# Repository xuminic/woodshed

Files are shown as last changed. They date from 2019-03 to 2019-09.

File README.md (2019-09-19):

# Wood Shed -- Howto build a wood shed

<table>
  <tr>
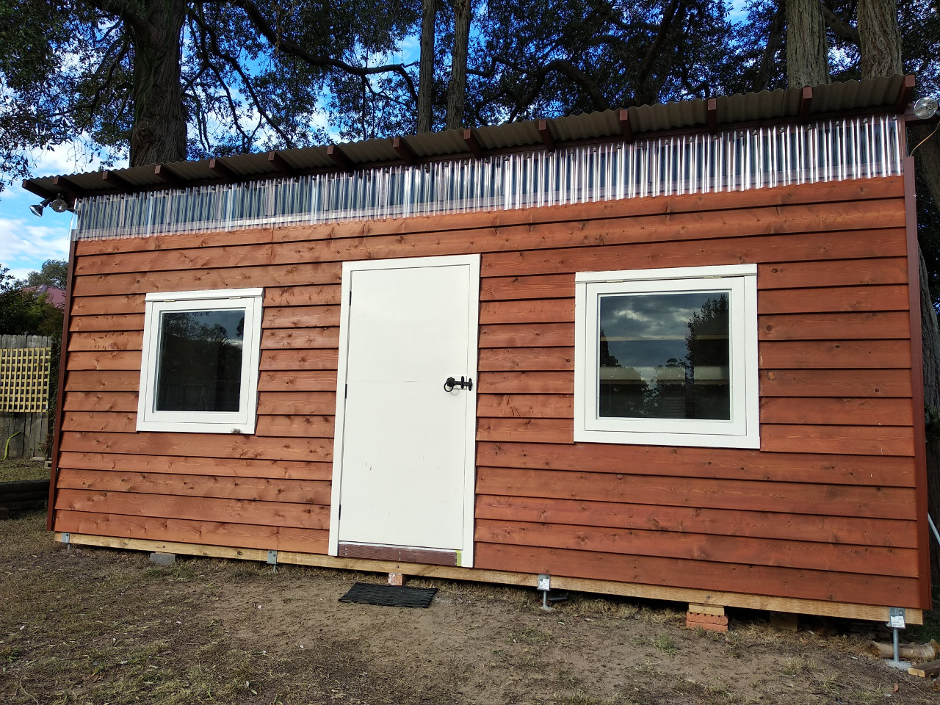
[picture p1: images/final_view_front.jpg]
Front View
    <td colspan="2"></td>
  </tr>
  <tr>
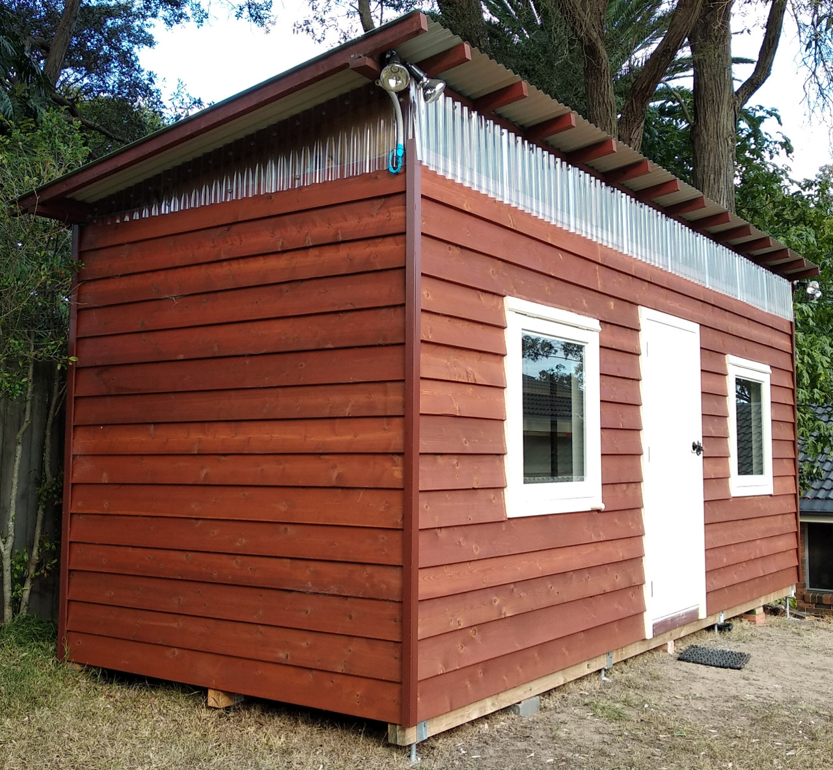
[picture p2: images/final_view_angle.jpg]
Angle View
    <td align="left"></td>
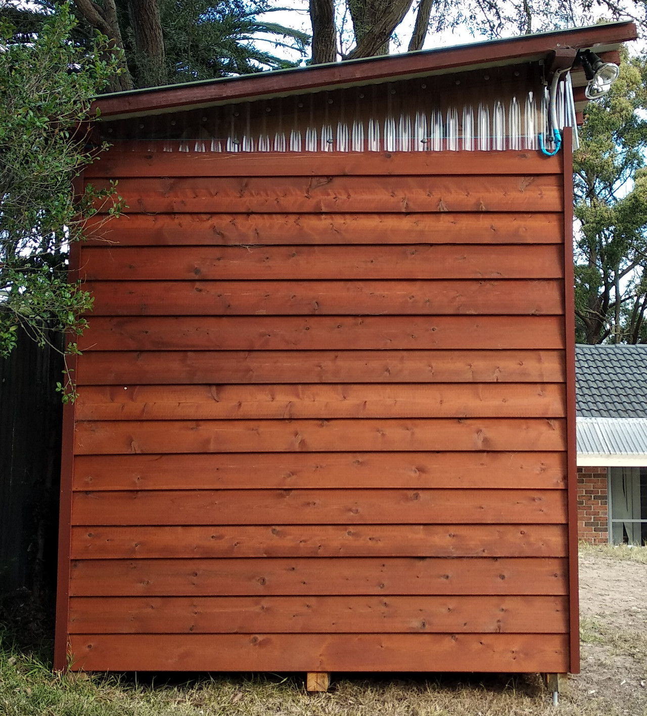
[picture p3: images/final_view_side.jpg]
Side View
    <td align="right"></td>
  </tr>
  <tr>
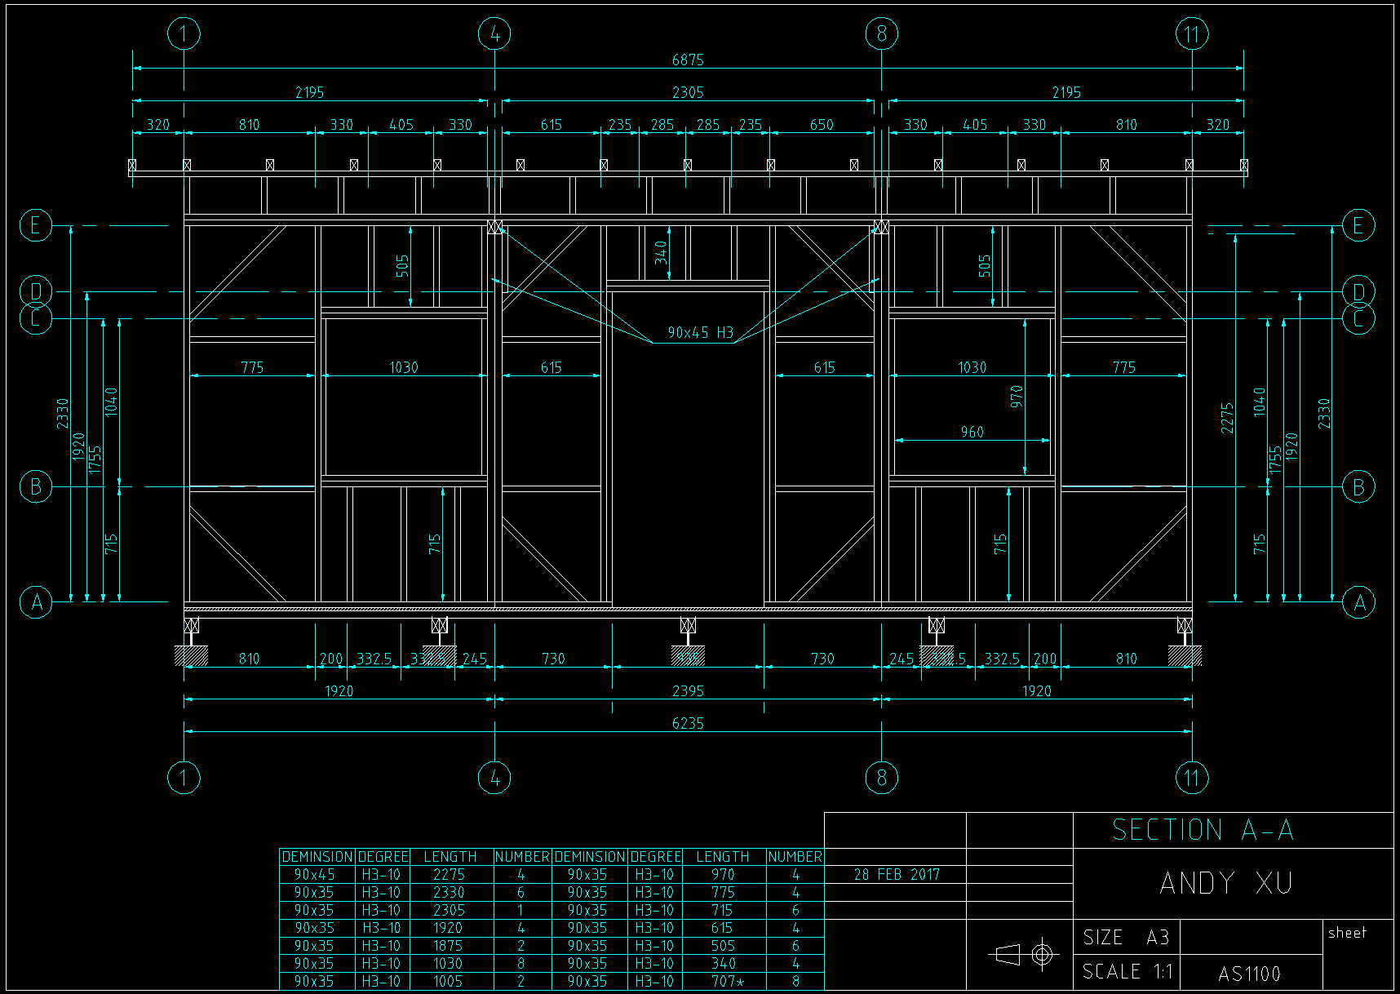
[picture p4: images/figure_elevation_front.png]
Front Blueprint
    <td align="left"></td>
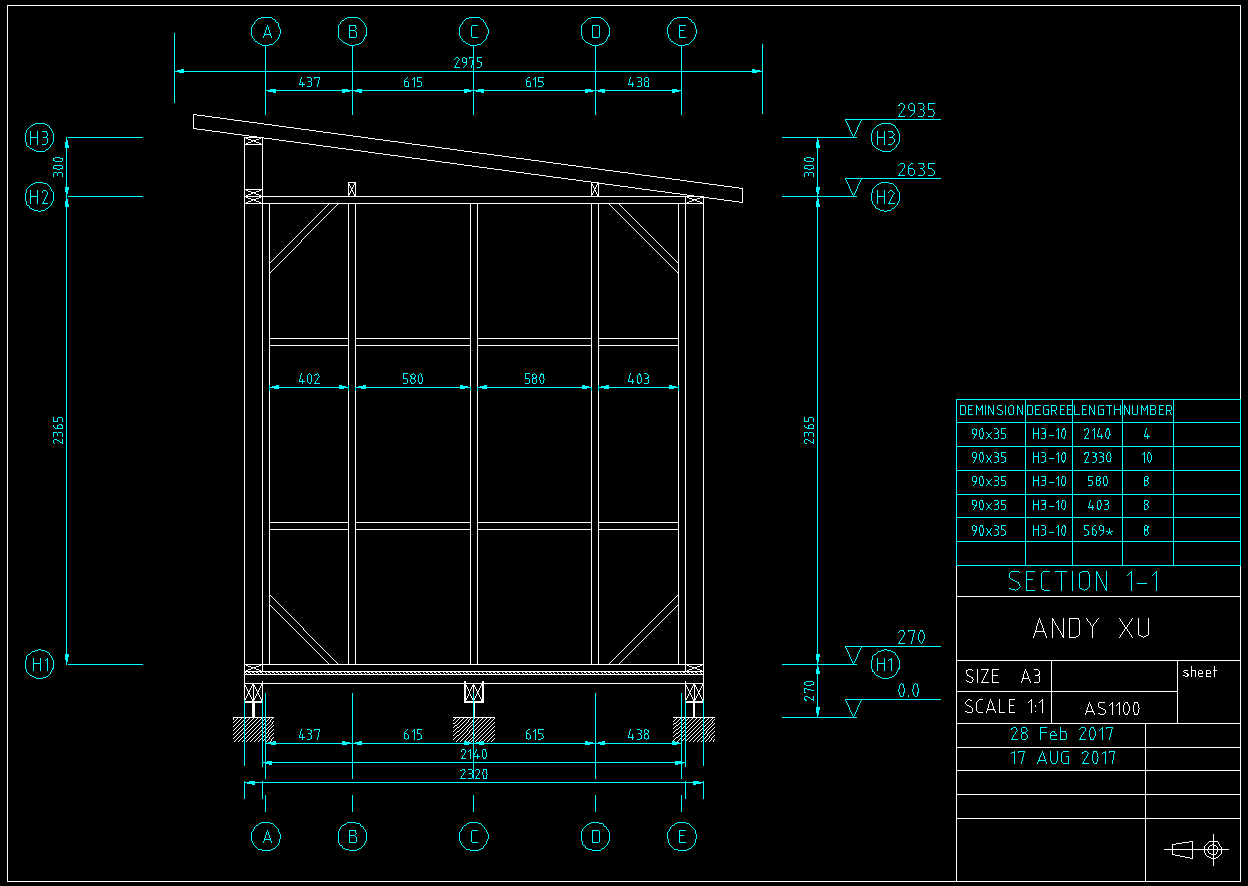
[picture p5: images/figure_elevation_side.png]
Side Blueprint
    <td align="right"></td>
  </tr>
</table>

This project shares my plan, progress and experience to build a small garden shed 
with wood frames and cladding. The roof is ColorBond metal and the foundation is
post anchor and concrete. The area is roughly 6 meters by 2.4 meters and the height
is 3 meters. The BOM budget was $4000 AUD and apparently was overrun, 
not sure the detail number, perhaps by 30%-40%. 

Most important part in this project is the plan made with LibreCAD. 
If you are a computer monkey who knows CAD software pretty well, and willing to
do some manual work in your backyard to kill some weekends, this project could be
a good start for you. You can easily shape it to fit your purpose.
If you don't know how to use LibreCAD, you may still find some useful references
from this project. I'll also export some PDF file from the plan.

## Motivation

I need a shed to host garden tools, being storage room and a sometime study room.
Metal shed is cheap but need the concrete slab to be assembled. Some wood sheds 
can be purchased from store. But they are not suitable for the slope.
Apparently whatever I do I need to build a flat foundation first. The easiest
way to build a foundation is deck foundation, just some anchor posts and timbers.
Naturally it would be quite strong if stick some timber frames on the timber
foundation and a shed could come into being, just need to do some detail design.
LibreCAD is a cross platform open sourced 2D CAD software which is perfect for 
my purpose. It supports layers so you can easily see through different profiles.
It is also convenient to design something not available in Internet, like this
one, had a 3:1 length width ratio.

## Disclaimer

This project is released under MIT License. Please find the attached LICENSE file.

This project is just for fun and for non-commercial use. All information 
in this project were deduced from basic physics or searched from websites. 
I am no architecture nor home builder. There is absolutely no warranty for the project.

There are some URLs and products descriptions linked to some commercial websites.
Those are all examples for helping understanding. There is no advertisement or 
promotion for ANY commercial entities. You are free to choose any suppliers for 
any brands of products.

When you get into the construction, do not forget to wear the proper protections
like helmet, goggles, etc. Be extremely careful with power saws and air tools,
which could easily cut some fingers off in no time. Be extremely careful with 
power lines, which could cause fire or even electrocution. Keep kids and dogs away
from work site.

Before you start, check with your local council to make sure the shed can be legally built.
Different council has different regulations regarding to the dimension.

The frame section is 90x35mm and the space is based on 600mm, which is commonly 
used in house building. However I do not know how strong it can resist against the wind
so please do not build it in tornado area.

## Files and Folders

Note that for some reason these .dxf files may suffer display issue in LibreCAD 2.1.x.
By such circumstance please try open them with LibreCAD 2.0.x.

    .
    ├── 01_foundation           # the design and details of the foundation and floor.
    ├── 02_frames               # the design and details of the structural frames.
    ├── 03_roof                 # the design and details of the roof structure.
    ├── 04_cladding             # the design and details of the timber cladding.
    ├── 05_interior             # some details of the interior design and utility shelf.
    ├── elevation_front.dxf     # the all in one CAD of the elevation in the front view.
    ├── elevation_side.dxf      # the all in one CAD of the elevation in the side view.
    ├── plan.dxf                # the all in one CAD of the plan view.
    ├── supply.ods              # the pretty rough BOM breakdown, don't rely on its price list.
    ├── images
    ├── LICENSE
    └── README.md

## Nail or Drill

When fastening timber frames, joinsts or beams together, professional trademen
prefer to use nails. The cost is low, probably $20/1000 nails. It's super fast
with an air nailer, for example, the project like the shed can be done in one day
in an experienced hand. However nailing is not as simple as it looks like. 
It needs skill. The nails could be bent or crooked. Thumbs are always under threaten.
Air nailer is not easy to use either. I have a compressor and frame nailer
and found it's quite hard to control the accuracy and direction. It always goes to
the unexpected place. It's heavy and loud, sometimes splits timbers. 
I reckon one needs thousands of nailing practise to get used to that.

Finally I gave up the frame nailer, I still use brad nailer by the way, but using
screws instead. Screws are very strong and very easy to control. It's accurate because
there's no impact while driving. It needs more money than nails, yet still only 
a tiny part in the whole project. Positively thinking, when you don't need the 
shed any longer, in theory it could be disassembled with a screwdriver.

For better performance, I recommands the Bugle Head Batten Screw, galvanised, 
heavy duty 14 gauge with hexagonal key drive head for high torque fastening.
Perfect for the 18V screwdriver.

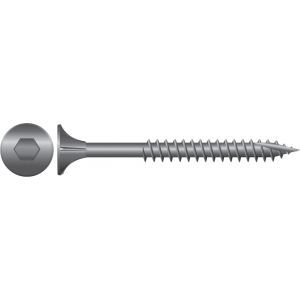
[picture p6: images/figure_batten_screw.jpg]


Most frame timber can be done with 65mm screws. The 100mm screws used to fasten
the frame on the floor. The overcross beam is 90x90 so there are 16 screws 
to be 125mm+. To get an accurate screwing, I always drill a pilot hole before
driving. For those longer than 100mm, the very long drill is needed.

## Power Tools in Need

Those power tools are very important to save your time and efforts. 
The professional tools are certainly the best. 
However even the cheapest one will also be the great helper.
The followed list is not a shopping guide. All pictures and brands are references only.
You may choose whatever you'd like in your local suppliers within your budget.

* Mitre saw is a must-have. It can easily cut timbers in 90 degree or 45 degress accurately in seconds.

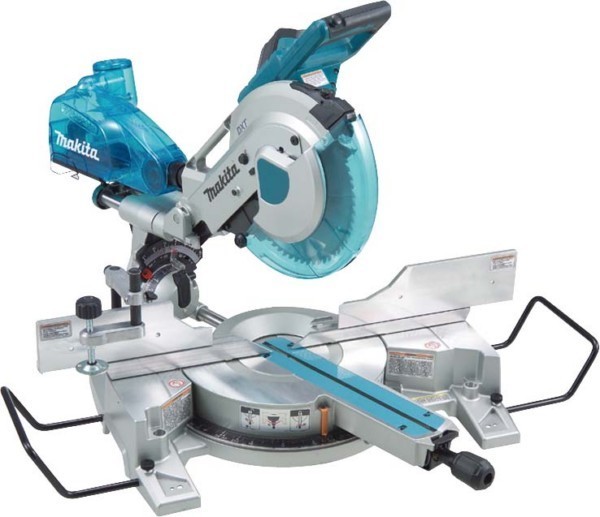
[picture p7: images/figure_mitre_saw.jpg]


* 18V drill set, normally includes an impact drill and screw driver. 
The 18V drill set are amazingly powerful and portable. I used it to drive a 150mm screws quite often
while 10V driver simply stuck.

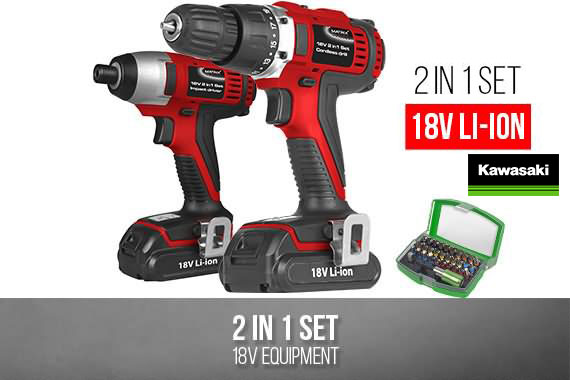
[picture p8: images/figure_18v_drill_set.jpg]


* Circular saw is almost the every-one-saw. You will need it when you cut the floor board.
It's light and easy to use. Sometimes it's more flexible when cutting large area boards.

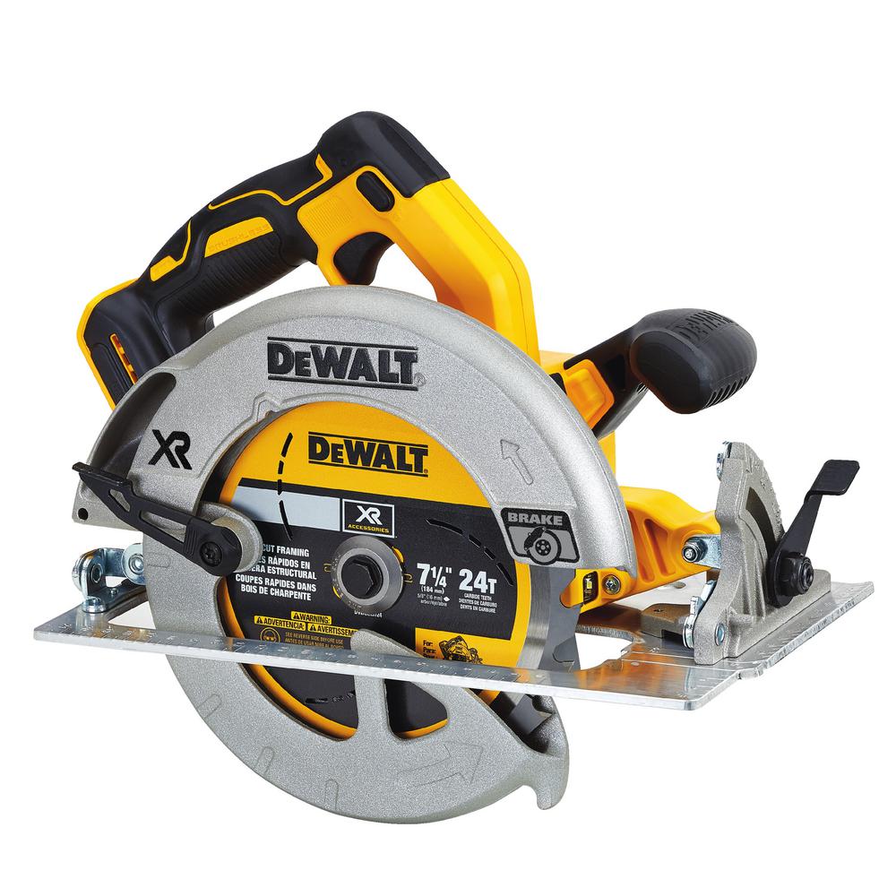
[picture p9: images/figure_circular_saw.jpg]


* Table saw is optional. It's more accurate than circular saw especially while cutting 
narrow or strip of boards. You will find it's much quicker while cutting the cladding board in length.

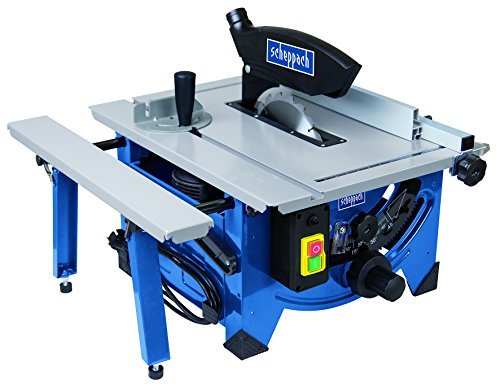
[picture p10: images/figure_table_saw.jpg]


* Drill press is optional. It helps to drill a vertical hole accurately. 
Perfect for the obsessive-compulsive personality.

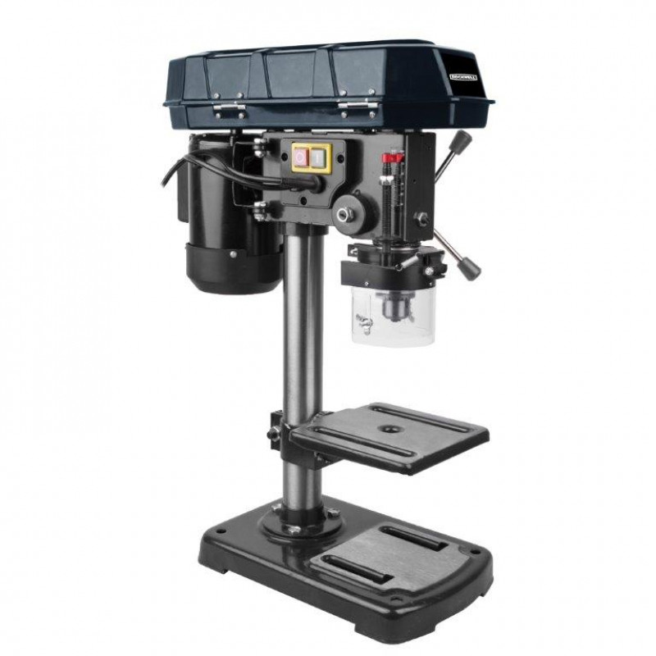
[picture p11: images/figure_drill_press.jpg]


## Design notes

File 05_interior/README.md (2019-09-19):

# Interior Improvement

As a garden shed, it was ready to use after exterior cladding. 
Morever than that I did a little upgrade to make it as cosy as a sometime reading room.
The upgrade includes the interior cladding, insulation, floor tiles, utility shelf and painting.

## Interior Cladding and Insulation

There are many building materials to be installed in door as the wall. 
Wood or laminate floor for example can be nice and stylish.
I chosed the plasterboard simply because its low price and been widely used.
The trade mark of the plasterboard is Gyprock, which is made of paper and plaster.

Before installing the plasterboard sheet, I prefer to install some supports around the edge.
It's not a have-to. Many builders choose to ignore it and install the plasterboard anyway.
But I feel it would be stronger with these extra supports.

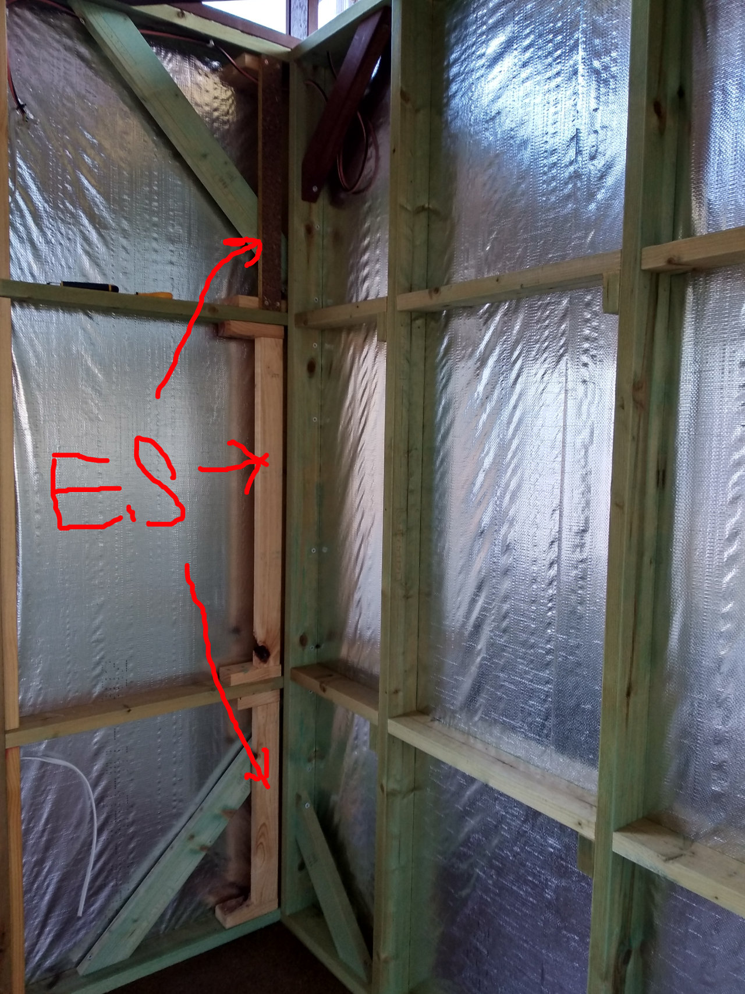
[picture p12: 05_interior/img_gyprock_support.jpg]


The red arrows point to the extra supports. Meanwhile all spaces between the studs were filled
with 90mm Earthwool. I don't know why I was so obsessive compulsively install the insulation
in a shed, probably by fashion. It's not expensive any way.

<table>
  <tr>
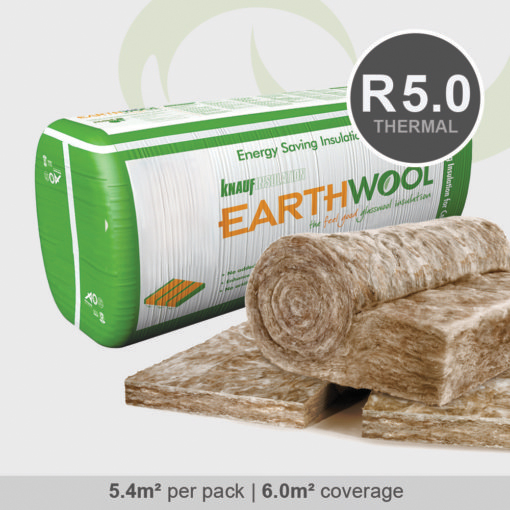
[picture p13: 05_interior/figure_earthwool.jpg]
Earthwool
     <td align="left"></td>
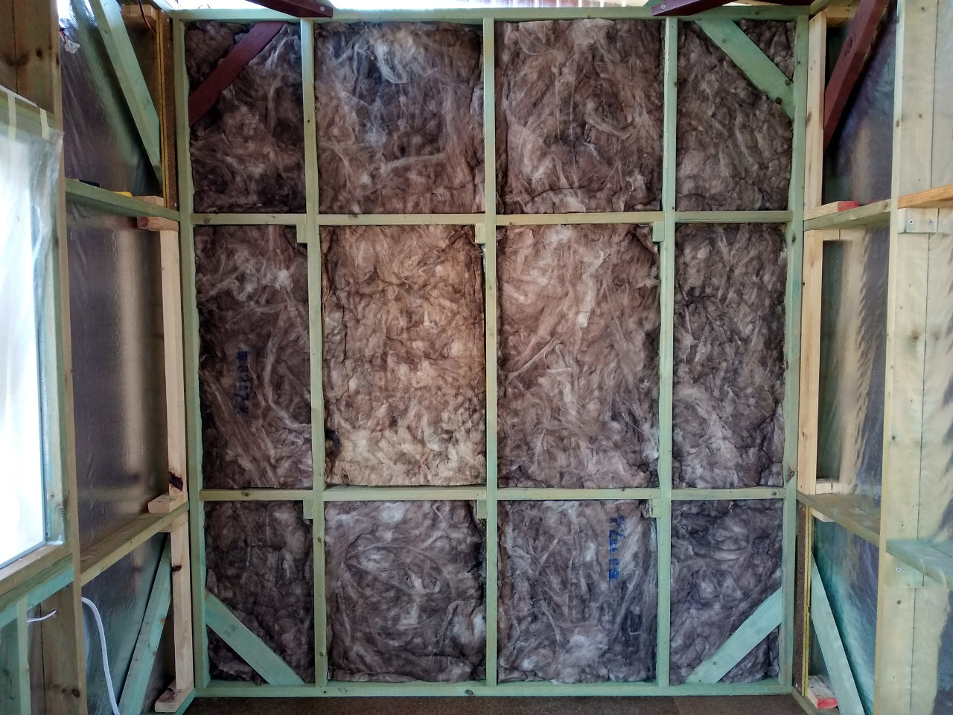
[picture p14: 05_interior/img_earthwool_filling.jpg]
Insulation
     <td align="right"></td>
  </tr>
</table>

If you want to wire power cable behand the wall, it's time to do so before gluing the plasterboard.
Generally the plasterboard should be glued to the stud with Stud Adhesive, only the edges been nailed.

<table>
  <tr>
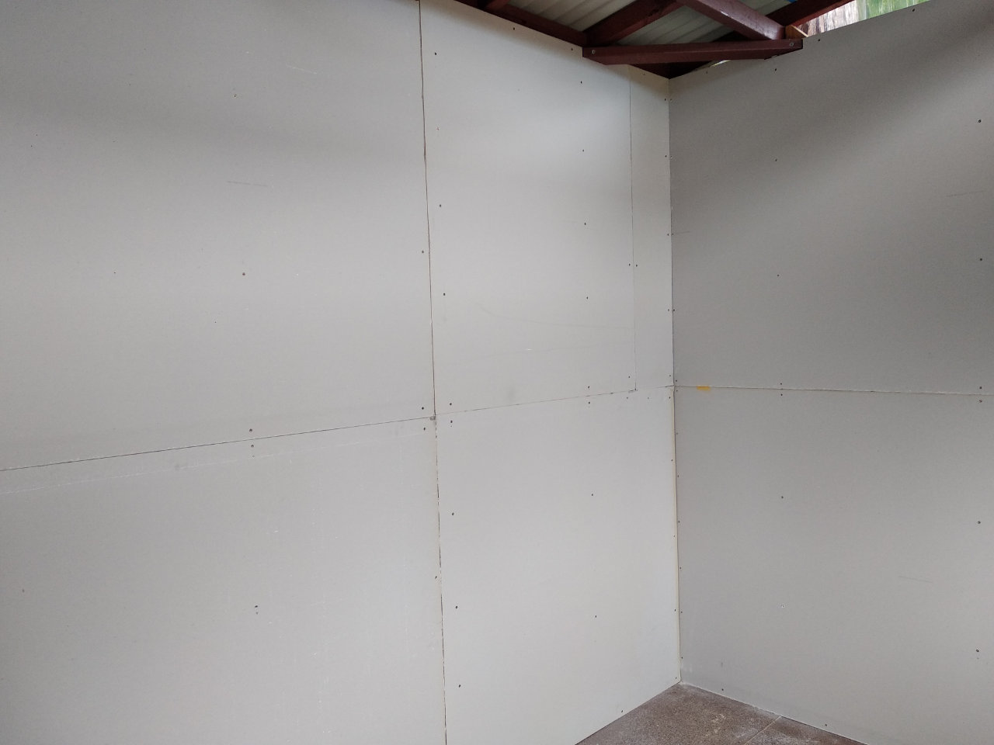
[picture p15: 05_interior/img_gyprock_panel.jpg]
Gyprock
     <td align="left"></td>
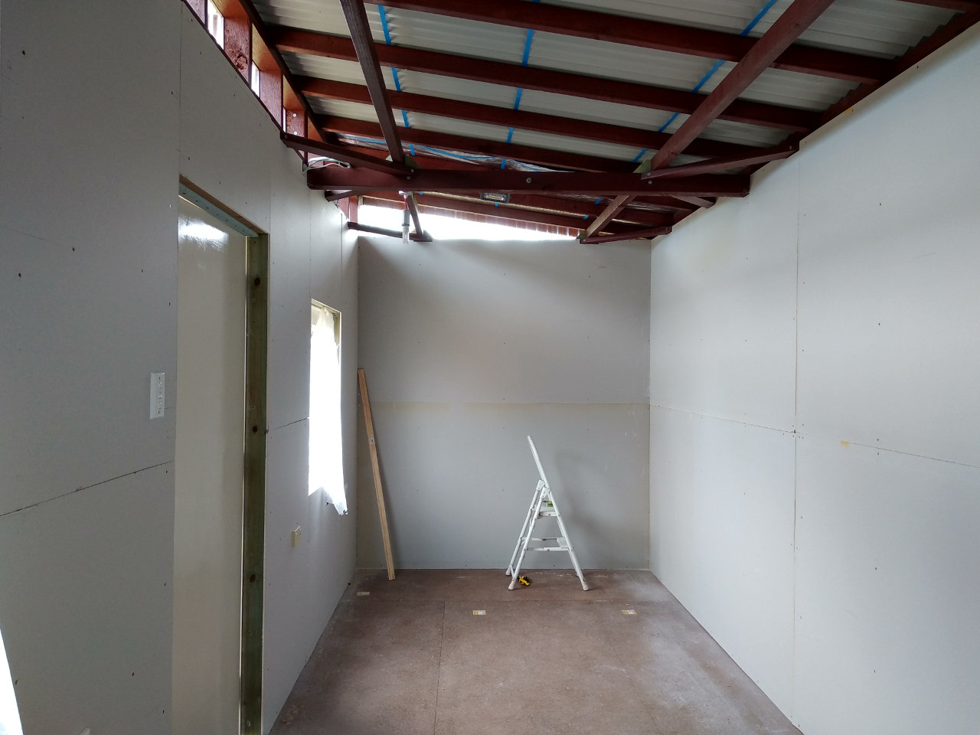
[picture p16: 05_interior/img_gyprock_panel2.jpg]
Gyprock
     <td align="right"></td>
  </tr>
</table>

The joints between plasterboards will be taped with Paper Jointing Tape and filled with joint Compound.
The process was quite tedious because I have to keep pasting and sanding to get a smooth finishing.

<table>
  <tr>
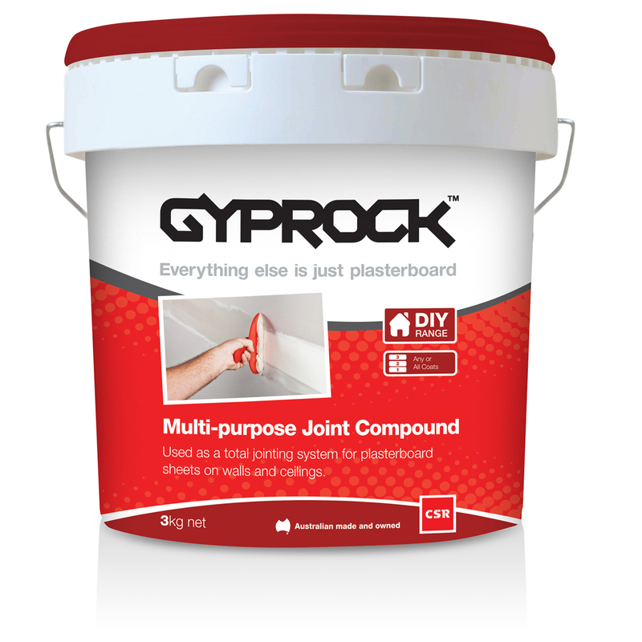
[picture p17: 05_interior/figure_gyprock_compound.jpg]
Gyprock Filler
     <td align="left"></td>
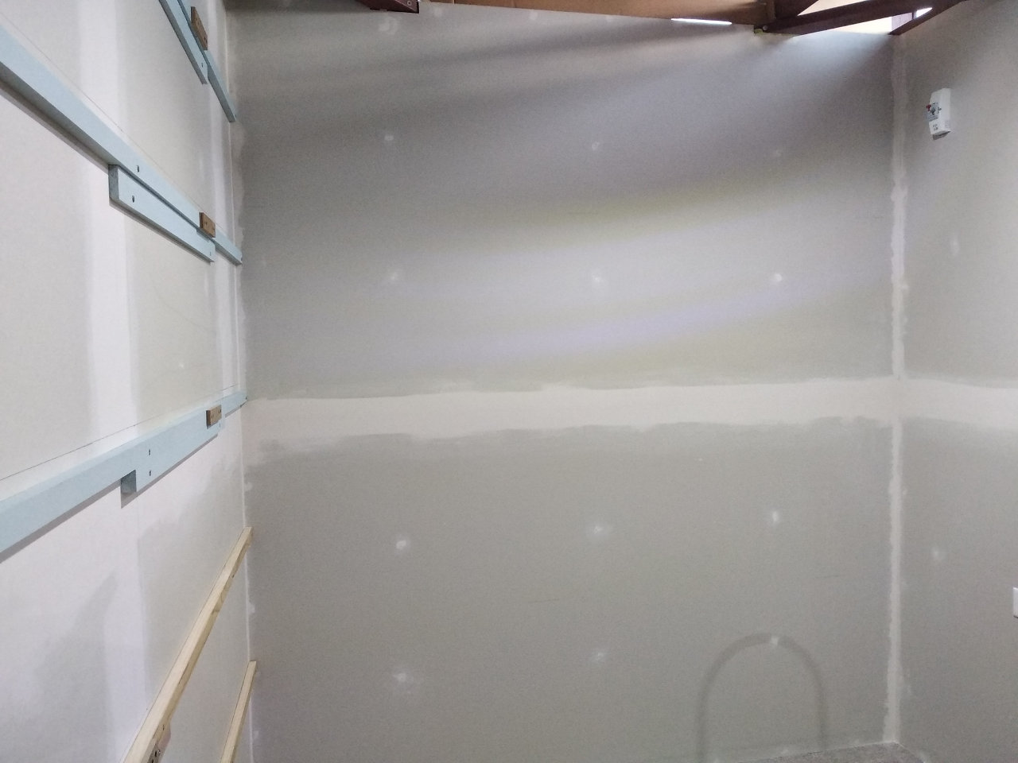
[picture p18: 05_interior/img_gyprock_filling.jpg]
Gyprock Filled
     <td align="right"></td>
  </tr>
</table>

Then the wall was painted.

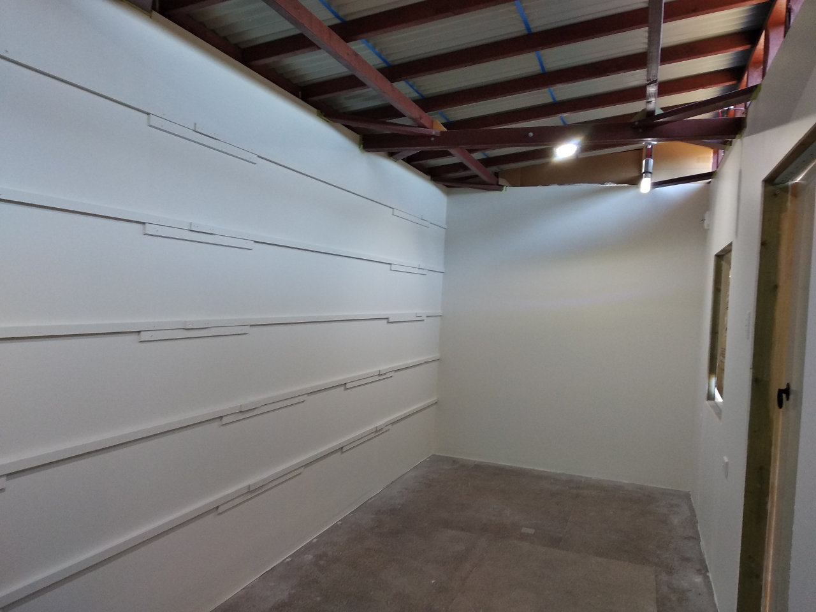
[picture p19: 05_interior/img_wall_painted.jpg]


## Floor Tiling

No more to say, just lay some tiles if you like, or leave it as-is.

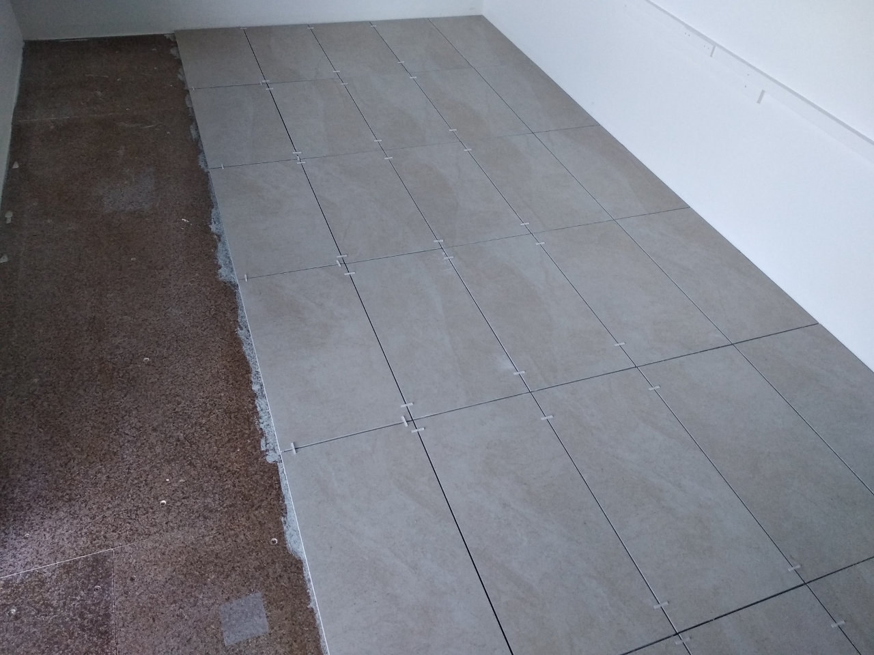
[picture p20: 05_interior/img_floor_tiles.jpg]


## Utility Shelf

The utility shelf is the most important component in the shed. After all it's a storage room.
This featured shelf has the same length to the shed. It occupied a whole wall. 
The back side supports of the shelf were nailed into the stud. The front side supports were installed 
to the frame timber, which stand on the floor and nailed to the roof structure.
The shelf is rigid and heavy duty.



The width of the shelf is slightly larger than common 300mm shelf; it's almost 400mm.
I think it's more versatile to use.

<table>
  <tr>
     <td align="left">Front View</td>
     <td align="right">Side View</td>
  </tr>
</table>

First, nail the supporting beam to the studs against the wall. 
I used the 42x22mm timber as the supporting beam.

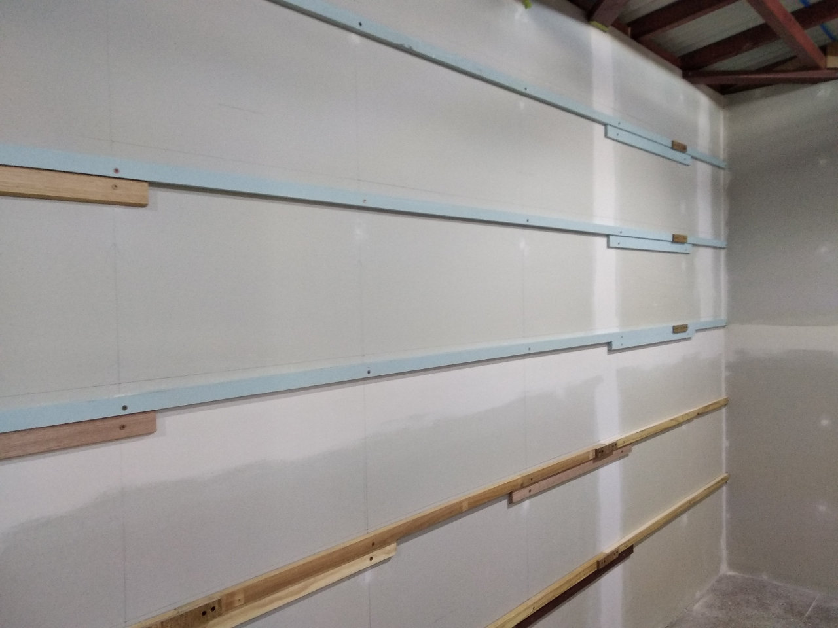
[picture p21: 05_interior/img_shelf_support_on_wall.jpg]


Second, install the posts. The posts are structural timber of 70x35mm. 
They stand on the floor. The ground end was nailed to a corner support.
The corner supports are also nailed to the studs. 
Note that each post must face to the studs.

<table>
  <tr>
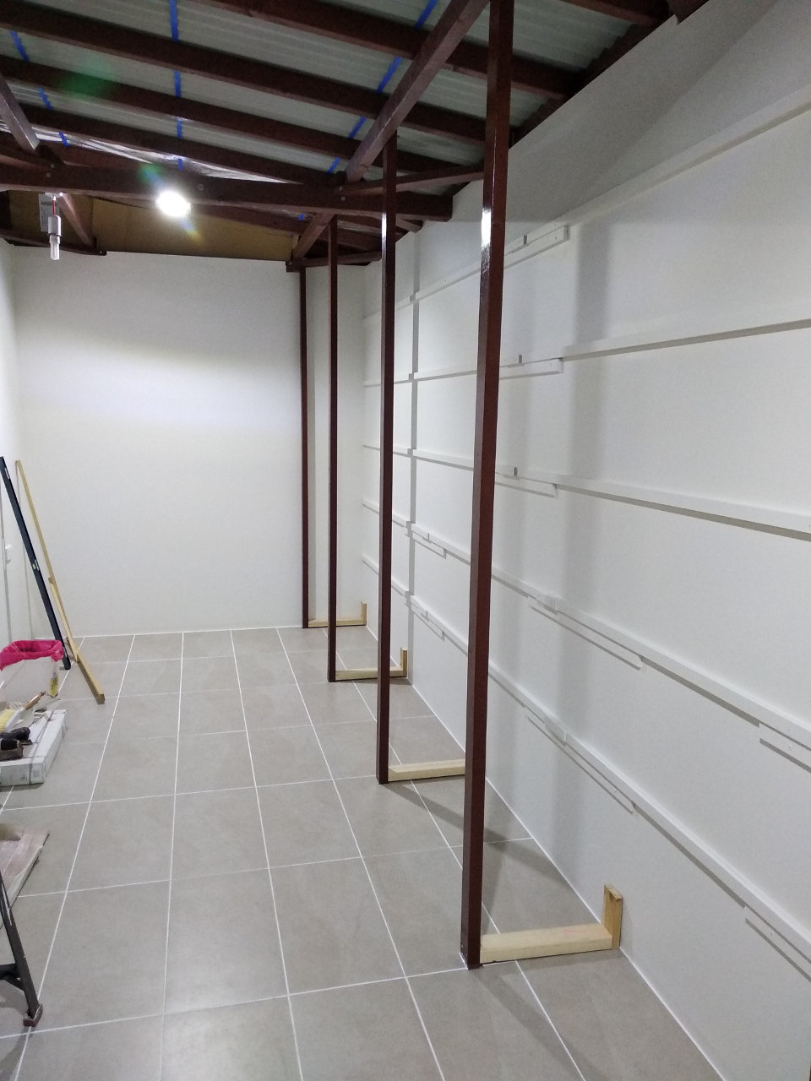
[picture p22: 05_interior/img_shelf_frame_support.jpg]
Post of Shelf
     <td align="left"></td>
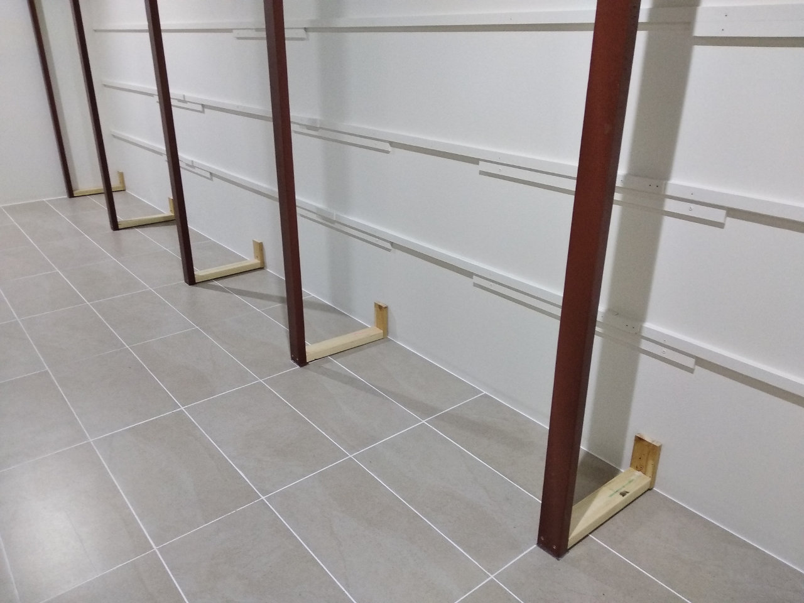
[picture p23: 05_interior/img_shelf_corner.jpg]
Corner Detail
     <td align="right"></td>
  </tr>
</table>

The upper end of the posts were nailed to the roof structure.
Remember the D-D in roof rack plan? It was designed for this.

<table>
  <tr>
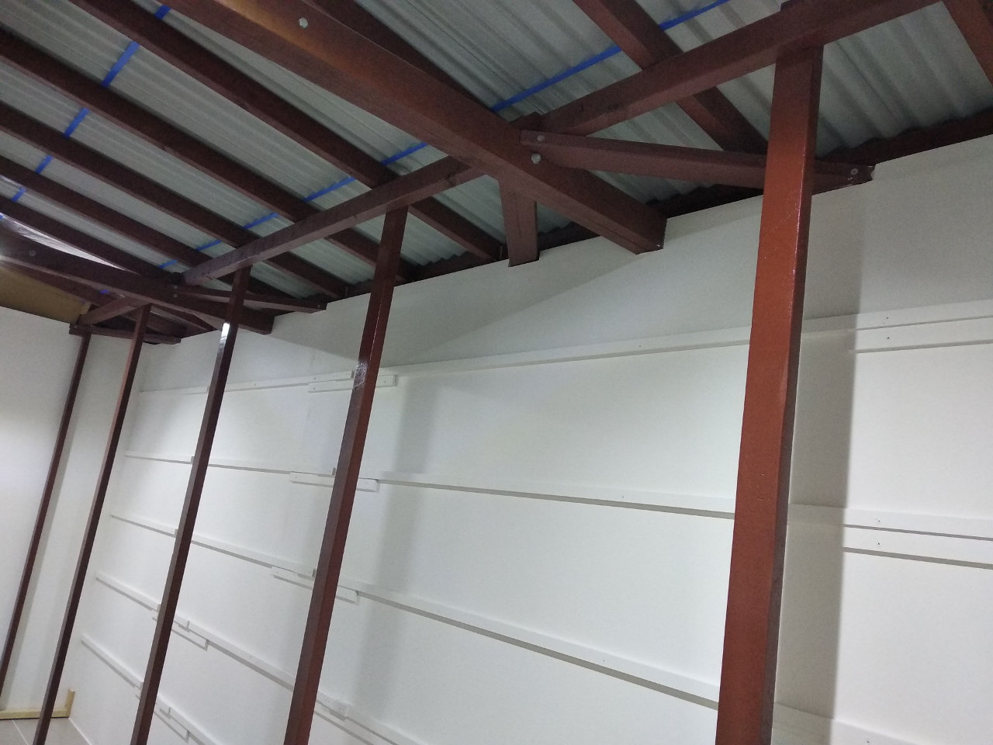
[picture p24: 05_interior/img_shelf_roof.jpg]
Post of Shelf
     <td align="left"></td>
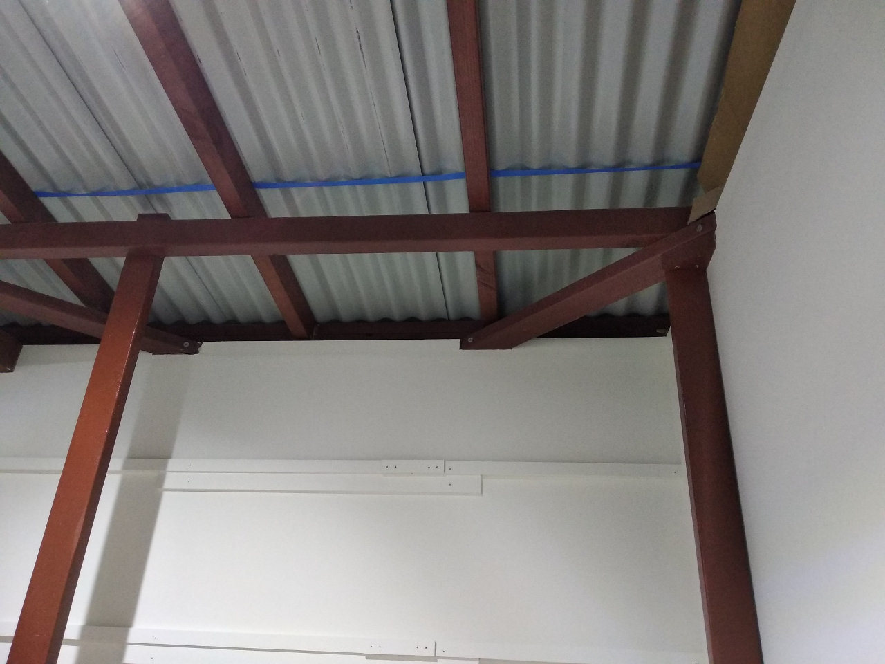
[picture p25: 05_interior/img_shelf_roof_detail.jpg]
Roof Detail
     <td align="right"></td>
  </tr>
</table>

Third, install the joists to the posts. The posts were standing on the ground, not nailed to, 
so it's not stable in horizontal direction. The joists would fix that, meanwhile give the support
to the shelf panel. I used 35x35mm timber as the joists. The joists must be levelled to the supporting beam
on the wall.

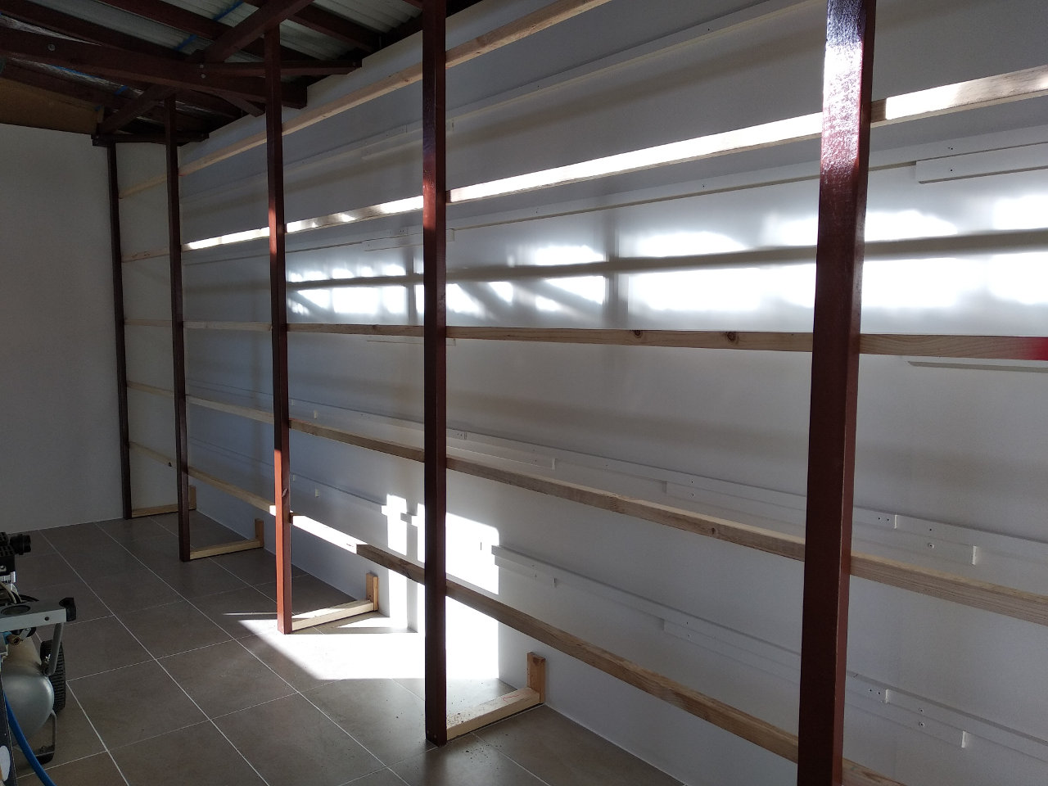
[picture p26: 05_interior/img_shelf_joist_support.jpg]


Finally, install the shelf panel. I used the laminate floor as the shelf panel, 
just cutting them to pieces in 400mm length and splicing them on the supporting beams and joists. 
The laminate floor is thin and hard, looked very stong for the shelf.

<table>
  <tr>
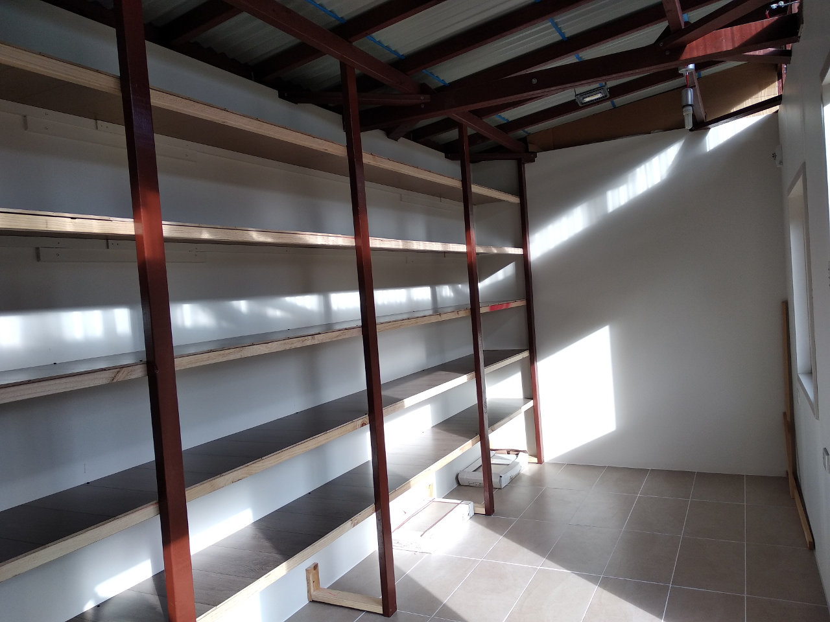
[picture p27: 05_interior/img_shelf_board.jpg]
Shelf Panel
     <td align="left"></td>
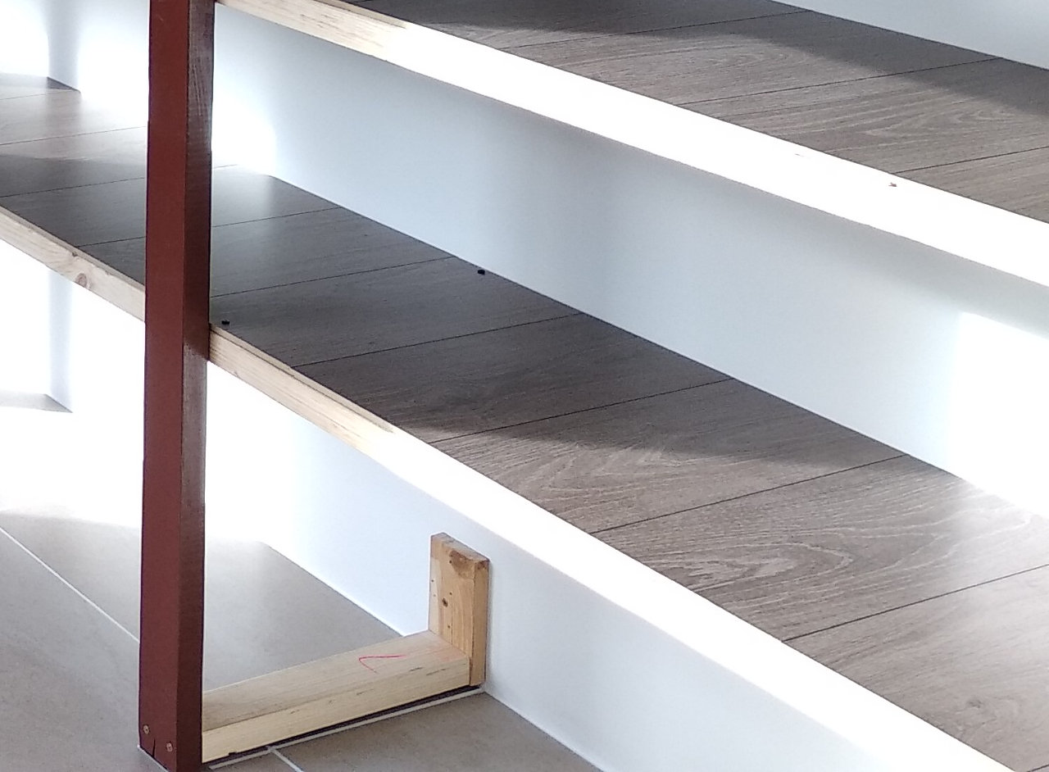
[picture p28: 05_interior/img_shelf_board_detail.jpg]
Panel Detail
     <td align="right"></td>
  </tr>
</table>

## Other Details

The effect of the roof windows. They are not covered by glass but by Polycarbonate Roofing Sheet.

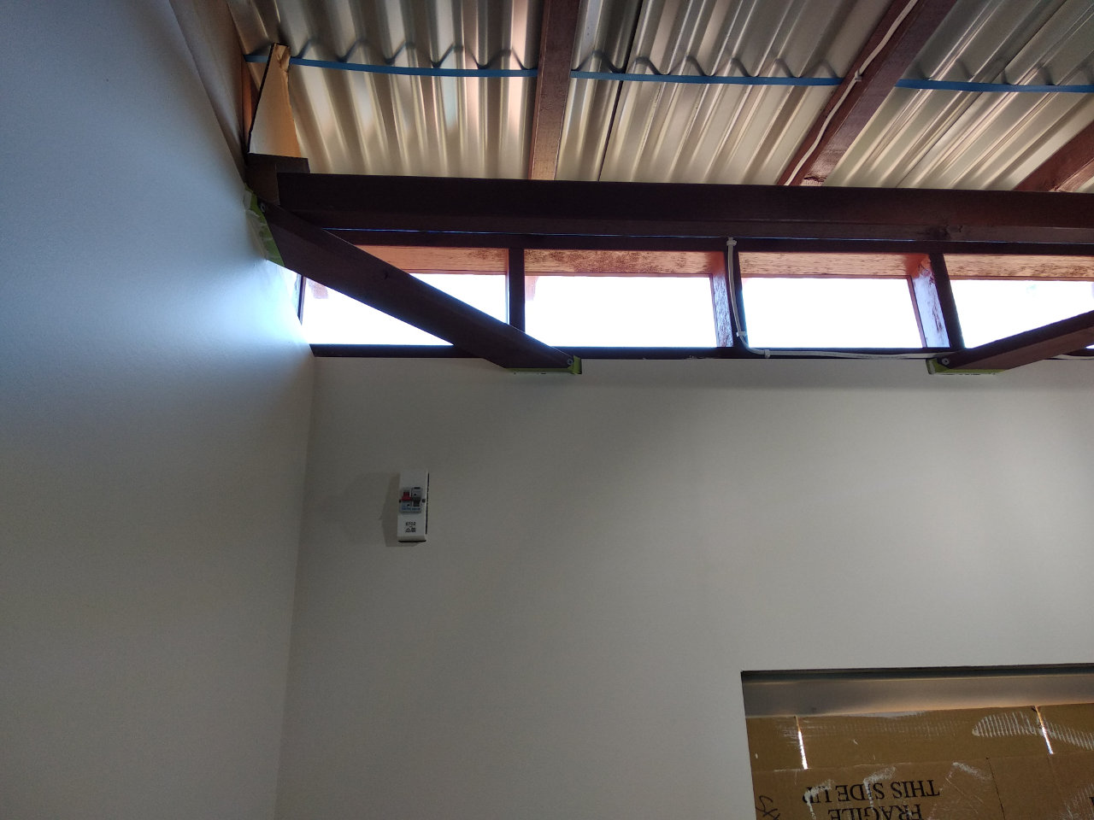
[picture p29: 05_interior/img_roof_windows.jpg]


Door and windows finishing, before and after.

<table>
  <tr>
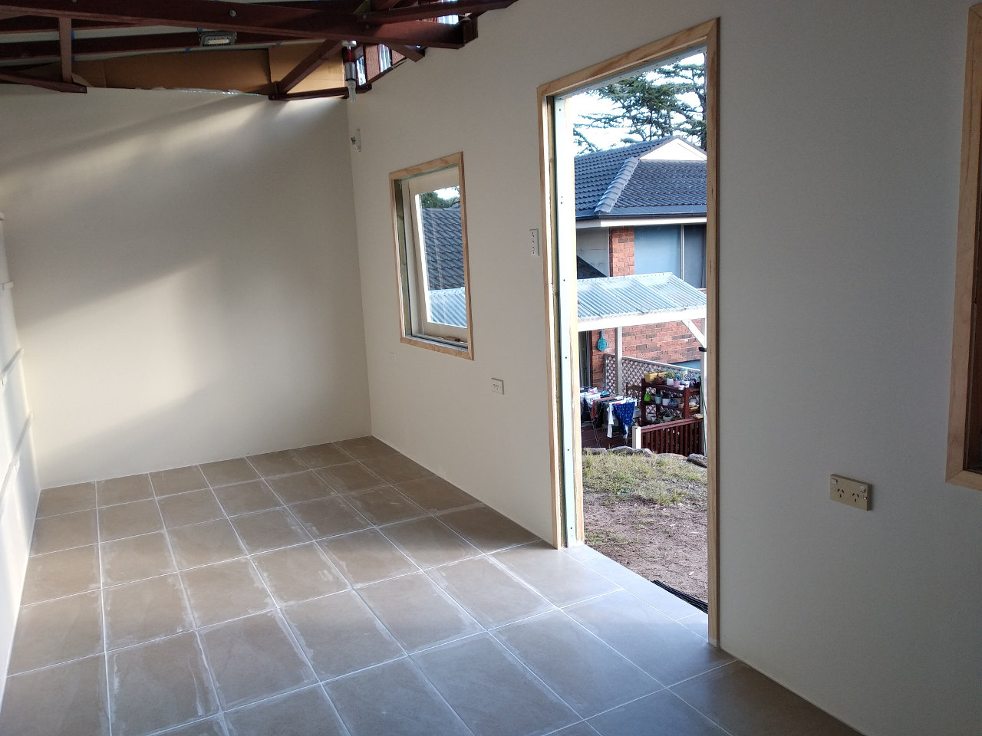
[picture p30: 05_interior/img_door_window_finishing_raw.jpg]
Before
     <td align="left"></td>
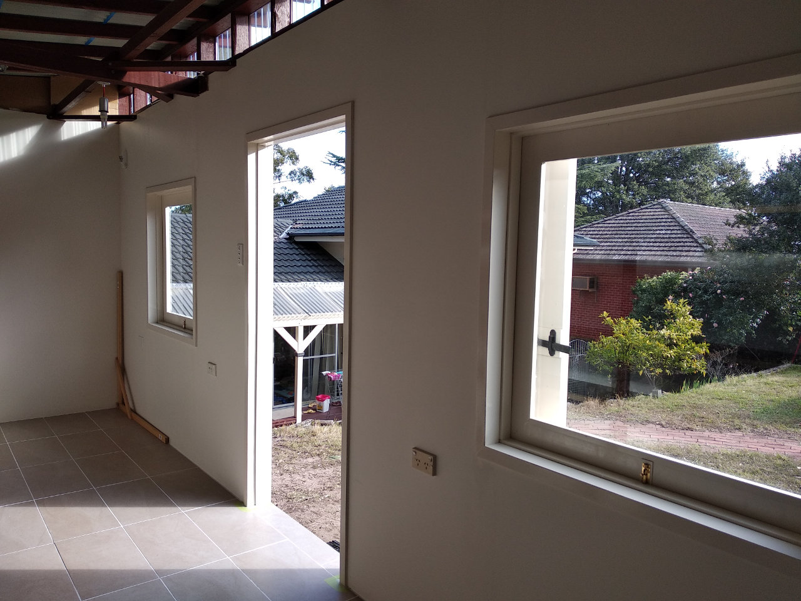
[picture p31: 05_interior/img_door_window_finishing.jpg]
After
     <td align="right"></td>
  </tr>
</table>

DIY windows. Cutting glass, all you need is a glass cutter.

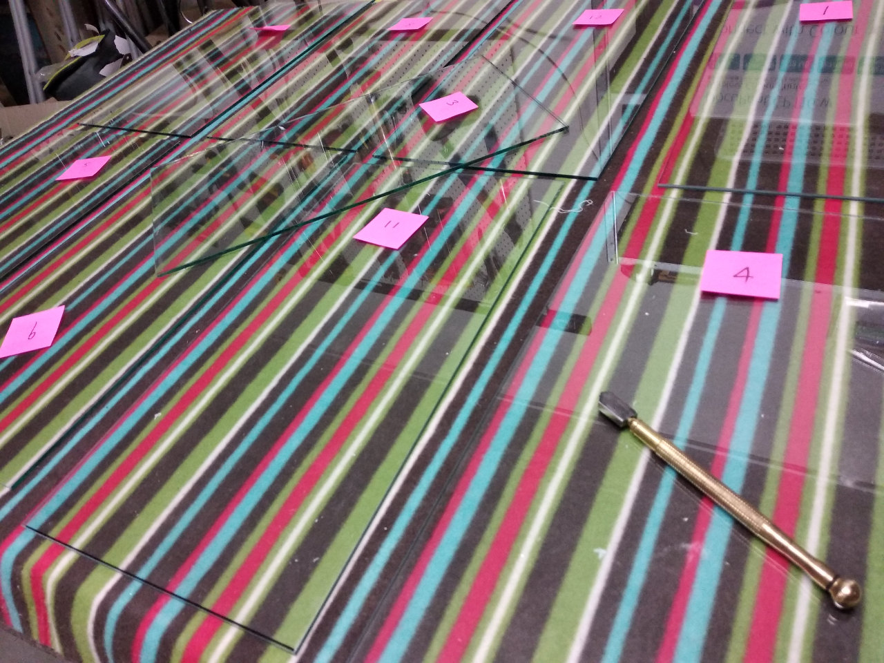
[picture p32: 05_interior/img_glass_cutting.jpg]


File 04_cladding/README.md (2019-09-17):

# Timber Cladding

The choise of cladding is vast. You are free to use anything as long as they resist wind and water.
I used to use blue board, which was cheap but a lot heavier, or plywood, which looked nice but needed 
to be carefully painted. This time I chosed the traditional cedar weatherboard cladding, the Beveled Siding.
It's not just low price for itself. The repairing or replacing is also much easier.

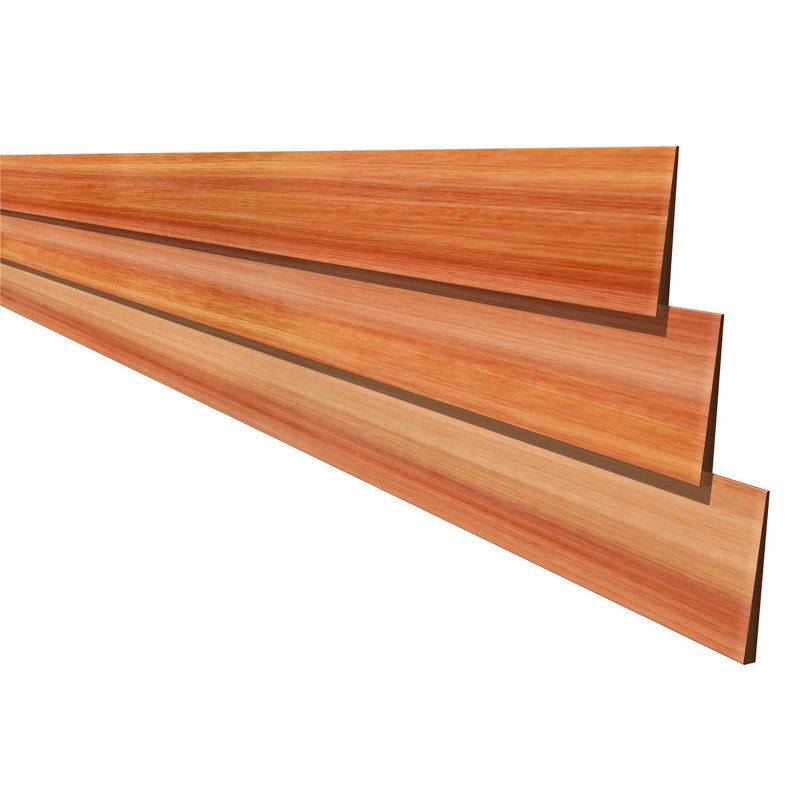
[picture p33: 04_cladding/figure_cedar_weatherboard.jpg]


## The Extra Supports

Before the cladding timber, the extra supports should be installed to brace the weatherboard. 
Precisely, some joinsts should be installed around the window frames and the door frame.
Or generally, anywhere between the studs where the weatherboards lands on.

The extra supports around doors and window frames shows below. The left one is the extra supports
and the right one is how the extra supports look in the whole structure.

<table>
  <tr>
     <td align="left">Extra Supports</td>
     <td align="right">Whole view</td>
</tr>
</table>

You may also add some simple decoration timbers to hold the weather board in position.
Usually they are in the cornor or in the door and windows frames. The decoration timbers
can be as simple as 70x35mm structural one.



## The Insulation Membrane

The building membrane is not commonly used in small project like the garden shed.
I installed the insulation membrane because I planned to install some internal boards
so the membrane can be a barrier to radiant heat, keep warm and provides a physical 
layer to protect against water and air infiltration. I chosed this kind of film:

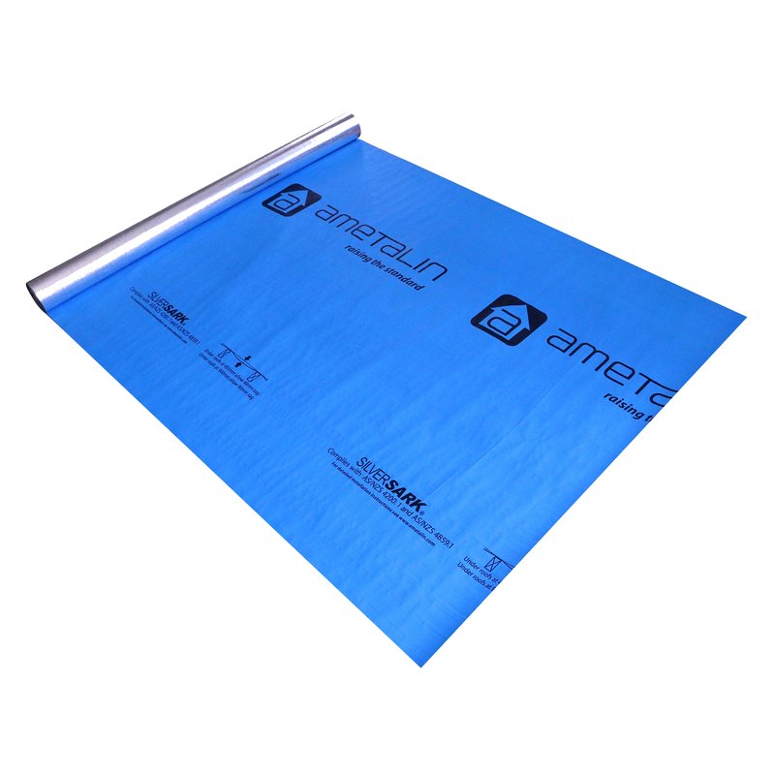
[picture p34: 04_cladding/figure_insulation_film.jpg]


It looked like this before cladding:

<table>
  <tr>
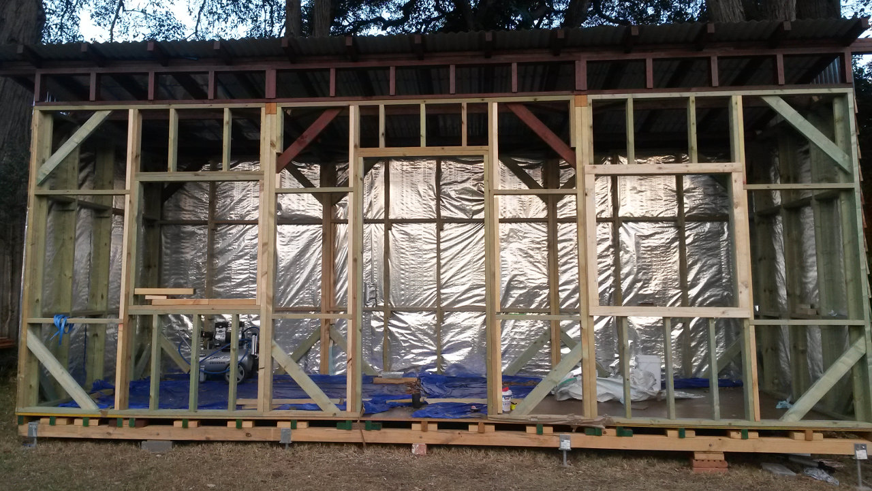
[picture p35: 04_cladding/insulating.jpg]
Insulating
     <td align="left"></td>
     <td align="right">Insulated</td>
</tr>
</table>

## Cladding

Cladding is fairly simple, just nail these boards piece by piece to studs.
Here is the plan:

<table>
  <tr>
     <td align="left">Front View</td>
     <td align="right">Side View</td>
</tr>
</table>

Note that roof structure was not cladding of weather boards. 
I used the polycarbonate roofing sheet instead.



It's cheaper than glass and much easier to cut.
It can be installed to the roof structure with roofing screw.

<table>
  <tr>
     <td align="left">Roof Structure</td>
     <td align="right">Roof Cladding</td>
</tr>
</table>

The picture shows the progress of the cladding



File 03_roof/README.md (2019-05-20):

# Install The Roof

## The Roof Enhancement

This shed has a single sloping roof. It's simpler and lighter than a pitched roof.
You even don't have to cut the Colorbond roof sheet.
However it's also not as strong as a pitched roof.
So before installing the roof, an enhancement structure need to be installed to 
improve its wind resistance.
The roof enhancement is combined by 12 triangle supports and 2 cross-over beams.
The plan can be found at <a href="plan_overhead.dxf">plan_overhead.dxf</a>



Please ignore the joints in B-B and D-D currently. They are not part of the enhancement but 
made ready for the shelf frames.

The triangle supports are installed in the top of the wall frames.
The cross-over beam in 4-4 and 8-8 are embedded into the wall frames. 



Each beam is combined by two 90x45 structural pines. 
I use the PVC glue and three M12 bolts to hold them together.
This structure can greatly improve the strength of the shed like a cage.
Actually the shed can stand still even the whole roof had been removed or replaced by other things.

Here are the detail pictures of the root enhancement.

<table>
  <tr>
   <td align="left">Cross-Over Beam</td>
   <td align="right">Beam structure</td>
  </tr>
</table>

## The Roof Structure

There is a roof frame, combined by three panels, installed in the front wall. 
All rafters are nailed on the top of the roof frame and the top of the back wall.
The roof frame is 300mm in height so making the front wall 300mm higher than the back wall. 
Here is the structure of the roof frame.



The roof frame is combined by three panels, just like the wall frames, which nailed together
and nailed onto the front wall frames.

<table>
  <tr>
   <td align="left">Panel 1-4</td>
   <td align="center">Panel 4-8</td>
   <td align="right">Panel 8-11</td>
  </tr>
</table>

When the roof frame is installed on the front wall, the whole structure is:



The plan can be found at <a href="elevation_roof_front.dxf">elevation_roof_front.dxf</a>.

The rafters are 70x45mm, 3 meters long structural timbers. 
The roof is quite small so I took away the joints, seated the roof sheet directly on the rafters.



The plan can be found at <a href="plan_rafter.dxf">plan_rafter.dxf</a>.

This is the side view at side wall A-E. You can see the slope roof rafter here.



This is the profile view at the cross-over beam 8-8:



The side view plan can be found at <a href="elevation_side.dxf">elevation_side.dxf</a>.

Here are the picture on site about the roof structure:

<table>
  <tr>
   <td align="left">Roof Front View</td>
   <td align="right">Roof Side View</td>
  </tr>
</table>

Once the roof structure is completed, the roof sheet can be installed immediately.
I used the corrugated metal roofing called COLORBOND. The in-store dimension is 3000x840mm
so I simply took 10 sheets installed without cutting.



Note that the screws must be roofing screws which have a rubber washer to prevent the rain water.
The screws must be fixed on the crest.

<table>
  <tr>
   <td align="left">Roofing Screw</td>
   <td align="right">Screw to Crest</td>
  </tr>
</table>

Here is what the roofing look like:



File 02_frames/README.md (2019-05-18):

# The Frame of the Wall Structure

The dimension of the shed is 6235 * 2320 * 2400 in millimeters. 
Building a 6 meters wall frame would be quite challenging for a hobby project.
So I separated the wall frames to 8 pieces, each 4 square meters around.

Here is the frame plan in window line:

Plan View

The CAD file can be found in <a href="./plan_frame.dxf">plan_frame.dxf</a>.

The 8 pieces are A1-A4, A4-A8, A8-A11, E1-E4, E4-E8, E8-E11 and two A-E.

<table>
  <tr>
    <td align="left">E1-E4</td>
    <td align="center">E4-E8</td>
    <td align="right">E8-E11</td>
  </tr>
  <tr>
    <td align="left">A-E</td>
    <td align="center"></td>
    <td align="right">A-E</td>
  </tr>
  <tr>
    <td align="left">A1-A4</td>
    <td align="center">A4-A8</td>
    <td align="right">A8-A11</td>
  </tr>
</table>

Note that
* Timber framings are graded structural pines. Most of them are 90x35mm.
* There are 8 pieces structural pines in A4, A8, E4 and E8 are 90x45mm.
* The 90x45mm notch in above panels, except the A-E panels, are made ready for the cross over beams.
* The cross over beams are also 90x45mm structural pines, 4 pieces all together.
* The 345mm extension in the upper panel of E1-E4 and E8-E11 are part of the roof structure.
* Each panel has some triangle supports. Do NOT tighten or install them before installation.

The A1-A4, A4-A8 and A8-A11 panel will form the front view of the shed. 
The plan can be found in <a href="./elevation_section_A.dxf">elevation_section_A.dxf</a>



The E1-E4, E4-E8 and E8-E11 panel will form the back view of the shed.
The plan can be found in <a href="./elevation_section_E.dxf">elevation_section_E.dxf</a>



The A-E panel will form the side view of the shed.
The plan can be found in <a href="./elevation_section_1.dxf">elevation_section_1.dxf</a>



When panels were being installed to the floor structure, the side of the panels would be nailed 
together by bolts or by screws. The bottom of the panels would be nailed down on the floor.
Note that the best practice is to screw to the joints. For examples:



When you are making these panels together, you probably need some temporary timbers to support
them in case of a sudden wind blow.



Once these frame panels being nailed together and secure on the floor, you may start to install
the triangle supports. The frame structure should be very stable even without the roof structure.



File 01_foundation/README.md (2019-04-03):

# Build the foundation

Not all sheds need to build a foundation. If you are lucky and have a flat concrete slab, 
you may just bolt it on the ground. Some hobby products even simply seat the shed on a couple
of bricks, which still can last a few years. My problem is a slope of grasses. 
I have to level it before anything starts. So here is the solution:

Dig 12 holes after measurement, the hole is roughly 30cm in diameter and 40cm in depth. 
Fill the holes with concrete and the post anchor. 20kg concrete each hole should be fine.
Level and align these post anchors carefully before the concrete is set.

The post anchor looks like this:

Post Anchor

The inside dimension is 90x90mm so a 90x90mm timber beam can be right sit on it.

My post anchor array looks like this:

Post Anchor

The plan can be found in <a href="./plan_post_anchor.dxf">plan_post_anchor.dxf</a>.



The concrete normally curds in 24 hours. However you'd better wait for 7 days to reach 80%
strength. Then the support beam can be laid on the post anchor and secured by bolts.
The total length of the beam is 6.2 meters. If you feel it's hard to find/process/transport 
this long beam, you may split it to 3 sections and each secure to the post. Be careful with
the conjunction, make it level and flat. By the way it's also a good chance to level your
foundation by inserting some hard material between beam and post.
If you have the 90x90 timber that would be great. Otherwise like me I used two 90x45 H3 
timber binding together, which is easier to cut and slightly cheaper than 90x90. 
This is my support beam:

Support Beam

The plan can be found in <a href="./plan_support_beam.dxf">plan_support_beam.dxf</a>.



The joinsts are sitting on the support beams to support the floor. 
It's a rather simple process, just nail those 70x45x2320 H3 timbers on the beam.
Please note my joinsts were not evenly spreaded on the beam, which was adjusted 
for support the edge of the floor boards. 
You don't have to do this. You may nail your joists evenly then adding some extra
joists to support the edge.

Floor Joinst

The plan can be found in <a href="./plan_floor_joinst.dxf">plan_floor_joinst.dxf</a>.



The floor is structural grade particleboard sheet so called Yellow Tongue,
which is named by its yellow edge.



The Yellow Tongue sheet can be as large as 3600x900mm. Surely the bigger the better
so just pick the size suits you. I chosed 1800x900 because it's lighter.

<table>
  <tr>
    <td align="left"></td>
    <td align="right"></td>
  </tr>
</table>

The plan can be found in <a href="./plan_floor.dxf">plan_floor.dxf</a>.



The front view and the side view can be found in 
<a href="./elevation_front.dxf">elevation_front.dxf</a> and
<a href="./elevation_side.dxf">elevation_side.dxf</a>.

<table>
  <tr>
    <td align="left"></td>
    <td align="right"></td>
  </tr>
</table>

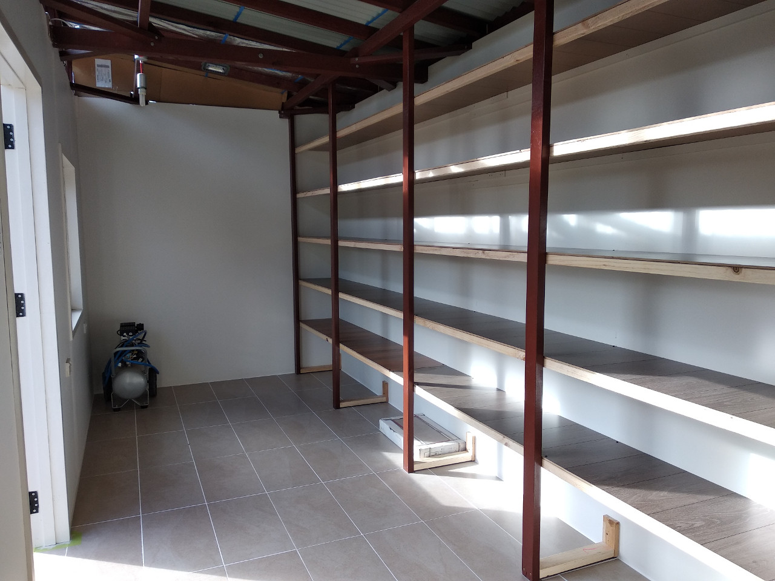
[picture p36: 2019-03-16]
images/final_shelf.jpg

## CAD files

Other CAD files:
01_foundation/plan_post_anchor.dxf
02_frames/fasten_frames.dxf
03_roof/elevation_side.dxf
04_cladding/frame_decoration_plan.dxf
elevation_front.dxf
01_foundation/plan_floor.dxf
02_frames/elevation_section_E.dxf
03_roof/plan_rafter.dxf
plan.dxf
01_foundation/elevation_side.dxf
02_frames/plan_frame.dxf
03_roof/elevation_roof_front.dxf
elevation_side.dxf
01_foundation/plan_support_beam.dxf
02_frames/elevation_section_A.dxf
03_roof/plan_overhead.dxf
01_foundation/plan_floor_joinst.dxf
02_frames/elevation_section_1.dxf
01_foundation/elevation_front.dxf

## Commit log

2019-03-18 Added CAD files.
    [elevation_front.dxf, elevation_side.dxf, plan.dxf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]
2019-03-20 Added some figures.
    [elevation_front.dxf, elevation_side.dxf, plan.dxf]
2019-03-25 Fixed the foundation direction.
    [elevation_front.dxf]
2019-03-27 Fixed the height of foundation timber.
    [elevation_front.dxf, elevation_side.dxf]
2019-03-28 Fixed some minor error in the main dxf file. Added the foundation page.
    [elevation_front.dxf, elevation_side.dxf, plan_floor.dxf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]
2019-04-03 Added the detail of the foundation.
    [plan_floor_joinst.dxf, plan_support_beam.dxf]
2019-04-04 Splitted the frame structure.
    [elevation_front.dxf, elevation_section_1.dxf, elevation_section_4.dxf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]
2019-04-09 Added details of the wall frame panel.
    [plan_frame.dxf, plan_overhead.dxf]
2019-04-09 Added description of power tools.
2019-04-10 Added a section about nailing or screwing.
2019-05-18 Added more stuffs in frame section.
    [elevation_section_4.dxf, fasten_frames.dxf, plan_overhead.dxf]
2019-05-18 roof initialized.
    [elevation_section_4.dxf, plan_overhead.dxf]
2019-05-19 Details added.
    [elevation_roof_front.dxf, elevation_side.dxf, plan_rafter.dxf]
2019-05-20 Added the details of the roofing.
    [elevation_section_4.dxf, elevation_side.dxf]
2019-09-17 Added the weather board cladding.
    [elevation_side.dxf, frame_decoration_plan.dxf, plan.dxf]
2019-09-19 Final piece added, the interior upgrade.
    [elevation_front.dxf]
